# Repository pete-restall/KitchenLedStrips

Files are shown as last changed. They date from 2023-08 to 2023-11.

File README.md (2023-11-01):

# Controller for Under-Cupboard RGB LED Strips
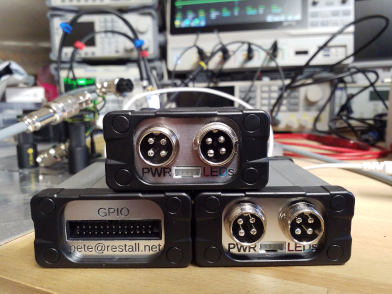
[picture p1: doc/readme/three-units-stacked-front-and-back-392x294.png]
Three Fully Assembled Units

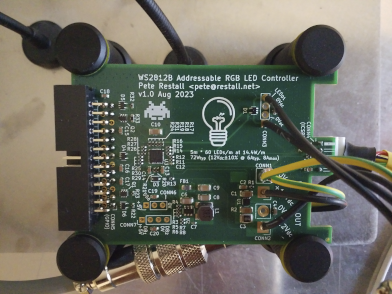
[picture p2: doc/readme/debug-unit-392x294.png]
Debug Unit on the Bench


## What is this ?
My wife wanted our new kitchen to have unobtrusive under-cupboard lighting.  It seemed like a simple and relatively quick project so I decided to have
a bash.  Buying off-the-shelf is boring - there's nothing like building something yourself to see why things work as they do or are priced as they are.
This repository is the result of my effort.

### The LED Strips
The LED strips are adhesive-backed tapes stuffed with RGB '5050' LEDs running at 12V and having a single data line.  The data line is essentially an
SPI MOSI with an implicit 800kHz clock configured as a daisy-chain; there is no start bit as is common with other 'clockless' or one-wire protocols so
the data is encoded using pulse-width modulation, a `1` being a long pulse and a `0` being a short pulse.  The tape has 60 LEDs per metre for a power
consumption of 14.4W/m.  Since the supply rail is 12V there are three '5050' LEDs are driven serially with an [SM16703P](doc/datasheets/leds/SM16703P.pdf)
controller providing a constant current of around 17mA.  The [SM16703P](doc/datasheets/leds/SM16703P.pdf) is _similar_ to the more common
[WS2812B](doc/datasheets/leds/WS2812B.pdf).

### The Slave (LED Controller Board)
The controller board I put together is intended to be very simple with few bells and whistles.  It is based around a
[PIC16F15355](doc/datasheets/mcu/PIC16F15355-DS40001853C.pdf) microcontroller.  The controller is fairly dumb in that it is intended as a slave device,
receiving infrared commands via a [TSOP34440](doc/datasheets/infrared/TSOP34440.pdf) and then handling the generation of a frame buffer and its
serialisation onto the wire.  Each controller can output the frame buffer to one or two LED strips over CY 4-core control cable.  Over-current protection
for the LED strip power rail, as well as under- and over-voltage lock-out, are provided, as is a set of GPIO for future expansion.

The circuit was drawn in KiCad and the board was manufactured and assembled by JLCPCB.  To assemble the unit I soldered the through-hole parts (connectors
and wires) to the board and I cut the enclosure faceplates using a CNC router.  The firmware is written in assembly and is built using
[gputils](https://gputils.sourceforge.io/) since I keep forgetting how the Microchip XC8 compiler seems to deliberately produce bad code; redundant
`goto`s to eat cycles, that sort of thing.  The timing of the LED bitstream is tight enough using this microcontroller that such things matter.

### _[WIP]_ The Master (Voice Commands)
The project is being done in two stages.  The first stage is basic on / off control when you flip a switch.  That has been installed already and works
nicely.  The next stage will (the current work-in-progress) aims to allow voice control of the lighting without internet connectivity - no privacy concerns
or failed lighting when the rural broadband takes a dive.  Voice-to-intent _should not need an internet connection_.  Luckily there are frameworks that do
provide this such as one using an
[STM32F405 microcontroller and Picovoice](https://picovoice.ai/blog/offline-voice-assistant-on-an-stm32-microcontroller/)  A proof-of-concept I knocked
up in Python to control some other RGB LEDs in the house via infrared has shown this can work very well, with no model training required.

## The Repository
There are [Board Schematics](src/schematics).

As well as some [Photographs](doc/bench/photos).

There is the [LED Controller Firmware](src/firmware/lights-gadget).

Plus various [Documentation](doc) including [Datasheets](doc/datasheets).

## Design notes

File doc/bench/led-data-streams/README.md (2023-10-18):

## The Test Fixture
The test fixture is 18x LEDs (6x pixels) split into two partitions of 3x
pixels, ie. there are two strips of LEDs each with their own data wire but
shared +12V$_{dc}$ and 0V rails.

The first strip has its data line (D0) just connected to the cable's wire #3.

The second strip has its data line (D1) connected to the cable's wire #2 and
to the strip's ground via a 470pF 0805 MLCC.  This arrangement lets us compare
the effects of terminating the transmission line wth a moderate capacitance.

The test fixture is connected to the board via 1m of shielded 1mm$^{2}$ CY4
instrumentation cable (PELB0900).  The shielding is connected to the board's
enclosure but stripped back 4cm from the fixture and left unconnected.

## The Board
The board is fully assembled with all internal wiring and external connectors
and is placed inside the extruded aluminium enclosure, ie. a complete unit.

Only one pixel (3x LEDs) of each partition (strip) is addressed by the
firmware for these measurements.

## The Power Supply
The unit is powered by +12V$_{dc}$ supplied by a Rigol DP831 over 50cm of
shielded 1mm$^{2}$ CY4 instrumentation cable (PELB0900).  The shield is
connected to mains earth via the DP831 internally, which in turn connects to
the DUT's enclosure.

## The Oscilloscope
The oscilloscope is a 4-channel 2GHz Siglent SDS6054A.

The oscilloscope CH3 is probing the pad of the LED strip (ie. far-end from
the DUT, after the cable) that corresponds to the first partition (D0).

CH4 is probing the pad of the LED strip (ie. far-end from the DUT, after the
cable) that corresponds to the second partition (D1).

Both probes for D0 and D1 are PCBite 200MHz SP200 10:1.

CH1 is probing the pad corresponding to the +12V$_{dc}$ rail of the first LED
strip of the test fixture, using a Siglent 500MHz SP3050A 10:1 probe.

## The Measurement Results
The results of the measurements can be seen in the PNG screenshots and the
actual samples for channels CH1, CH3 and CH4 have been saved as CSV and are
in the `measurements-as-csv.tar.gz` tarball.

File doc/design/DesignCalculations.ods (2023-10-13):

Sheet: Capacitors
 |  |  | GRM21BR71A106KA73L | GRM155Z71A105KE01 | GRM155Z71A105KE01J | CL10B225KP8NNNC | CL05B104KA5NNNC
Capacitance
Nominal | 100 |  | 10 | 4.7 | 1 | 2.2 | 100
Nominal Adjusted for DC Bias | 92 | Look at the datasheet graphs for this; dependent on bias voltage and physical size | 6.83uF@3.3V, 4.73uF@5V | 3.972uF@3.3V, 3.212uF@5V | 0.598uF@3.3V | 1.95@3.3V | 92nF@5V
Min (-) Initial Tolerance (%) | 10.00% |  | 10.00% | 10.00% | 0.1 | 0.1 | 0.1
Max (+) Initial Tolerance (%) | 10.00% |  | 10.00% | 10.00% | 0.1 | 0.1 | 0.1
Min (-) Temperature Coefficient (%) | 15.00% | X7R is +/- 15% | 15.00% | 15.00% | 0.15 | 0.15 | 0.15
Max (+) Temperature Coefficient (%) | 15.00% |  | 15.00% | 15.00% | 0.15 | 0.15 | 0.15
Min Initial Capacitance | 82.8 |  | 6.147 | 3.5748 | 0.5382 | 1.755 | 82.8
Max Initial Capacitance | 101.2 |  | 7.513 | 4.3692 | 0.6578 | 2.145 | 101.2
Min Capacitance | 69 |  | 5.1225 | 2.979 | 0.4485 | 1.4625 | 69
Max Capacitance | 115 |  | 8.5375 | 4.965 | 0.7475 | 2.4375 | 115
Leakage Current
Insulation Resistance (ohm-Farads) | 1 |  | 50 | 50 | 50 | 484 | 1
Capacitance (uF) | 0.1 |  | 10 | 4.7 | 1 | 2.2 | 0.1
Rated Voltage (V) | 25 |  | 10 | 16 | 10 | 10 | 25
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

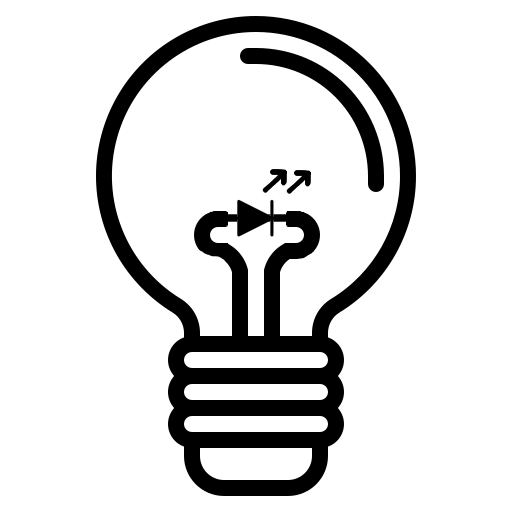
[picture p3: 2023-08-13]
src/schematics/kitchen-led-strips/led-light-bulb.png

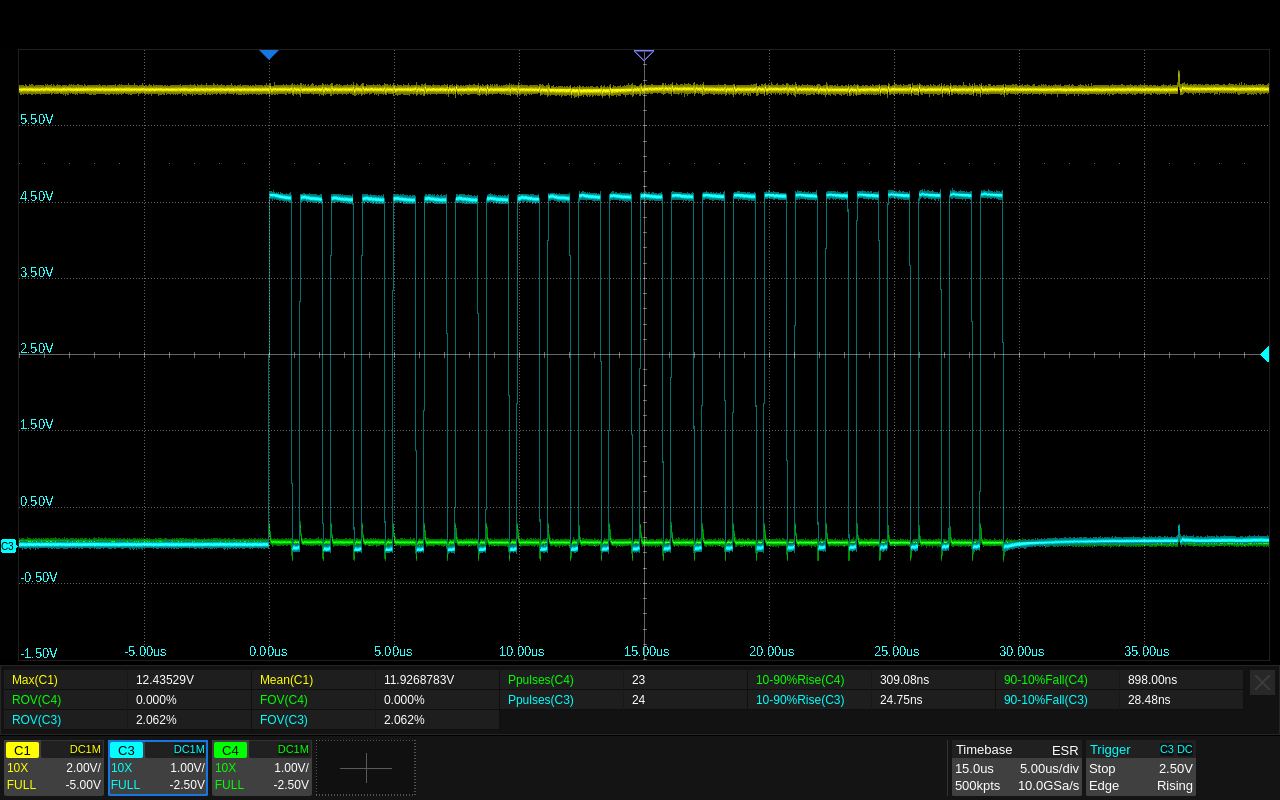
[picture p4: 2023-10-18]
doc/bench/led-data-streams/rgb-ffffff-slew.png

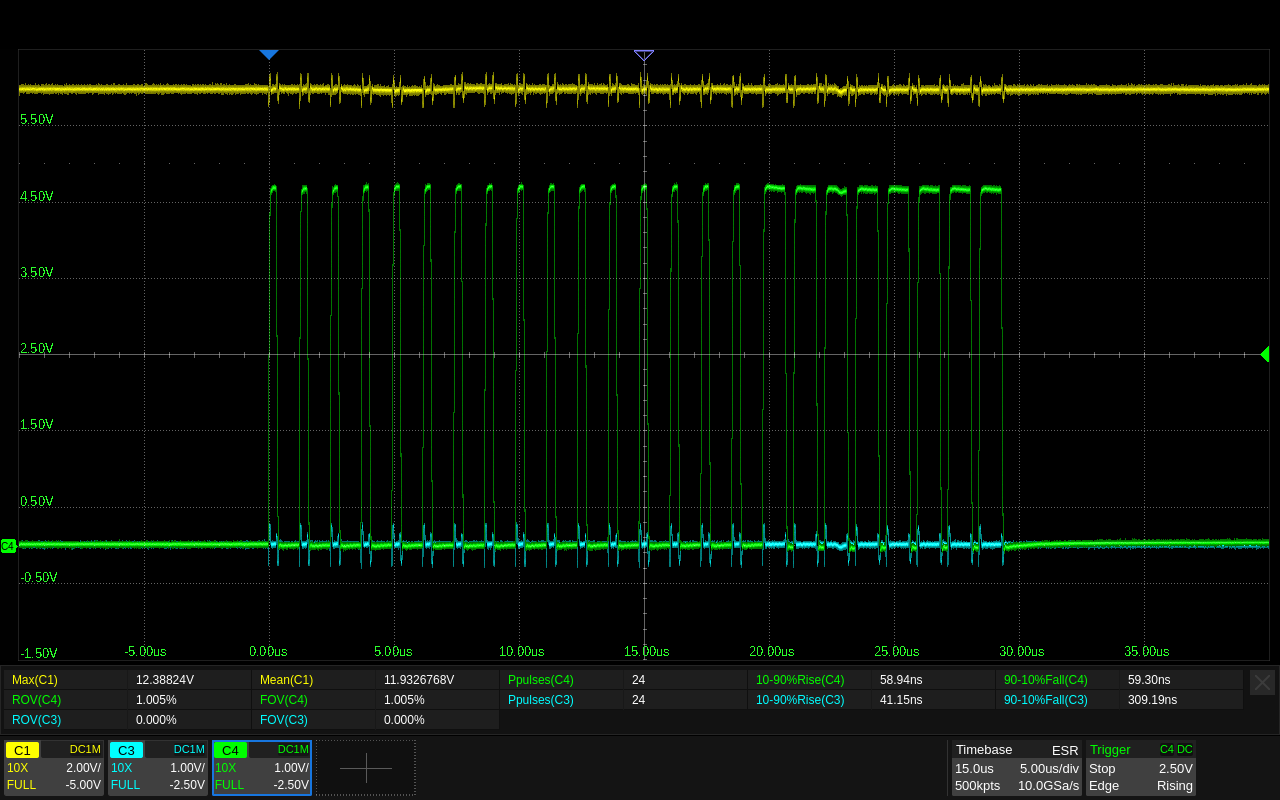
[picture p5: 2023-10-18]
doc/bench/led-data-streams/rgb-0000ff-slew-470pF.png

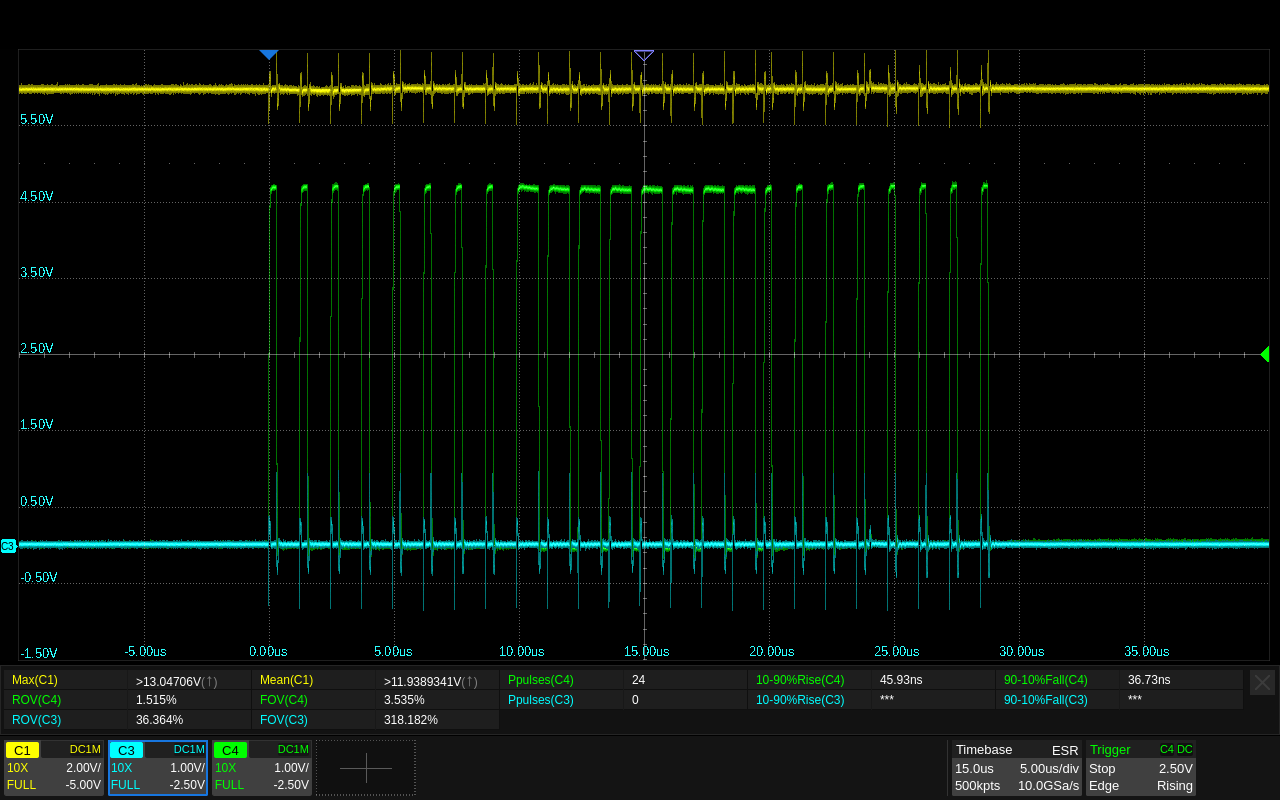
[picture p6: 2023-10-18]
doc/bench/led-data-streams/rgb-ff0000-noslew-470pF.png

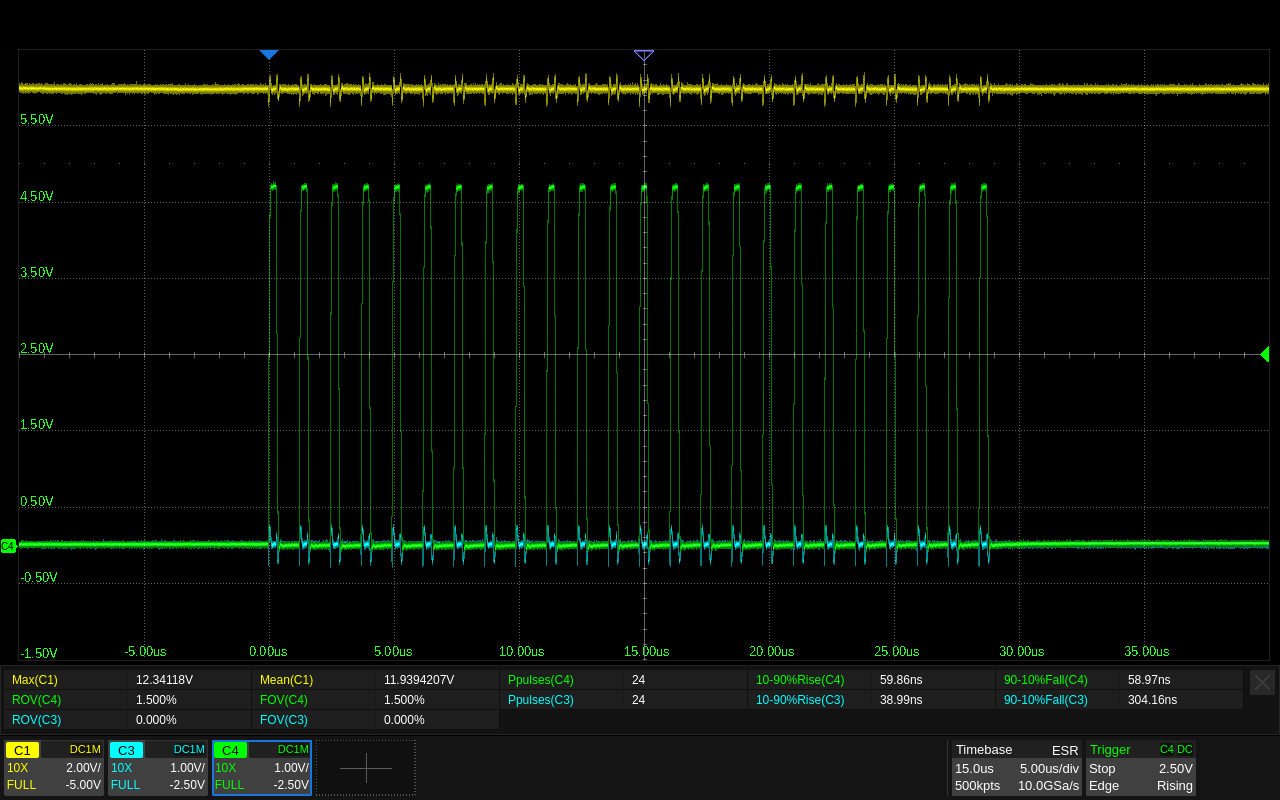
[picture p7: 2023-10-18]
doc/bench/led-data-streams/rgb-000000-slew-470pF.png

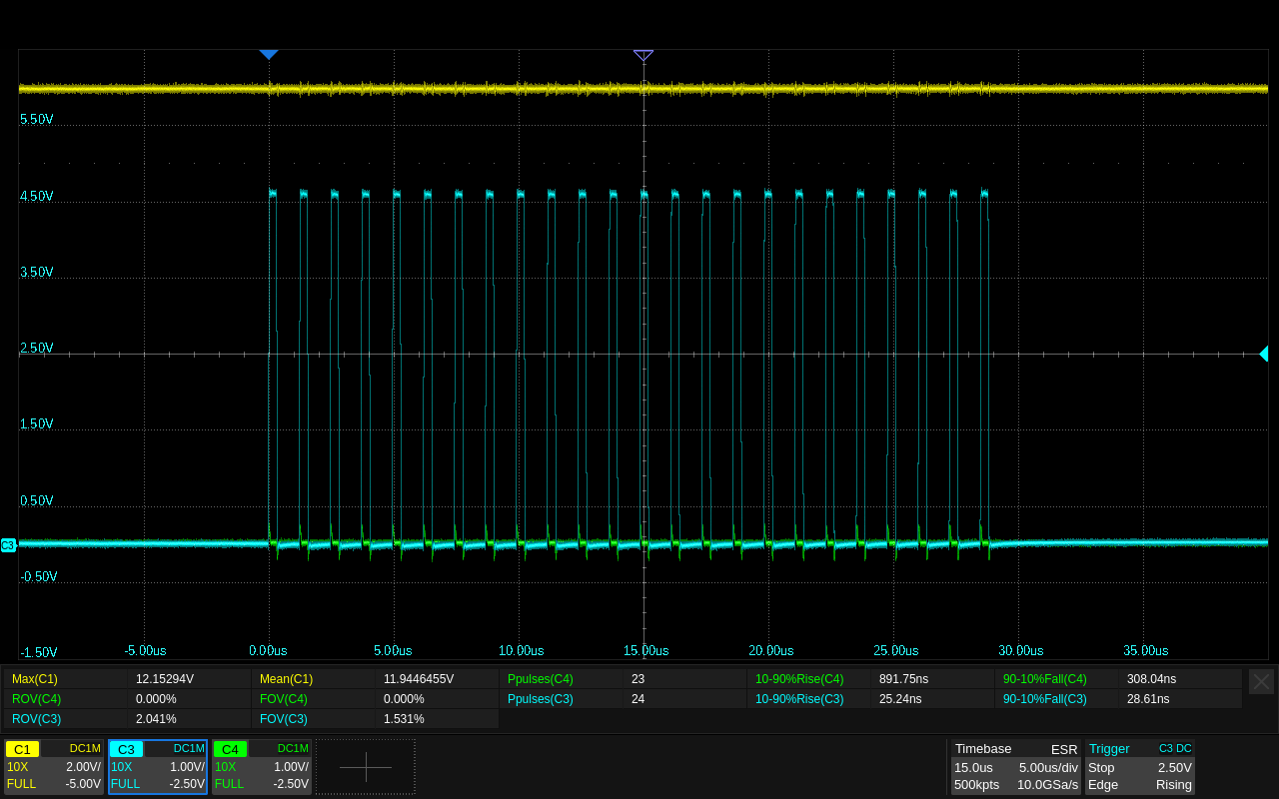
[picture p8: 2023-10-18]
doc/bench/led-data-streams/rgb-000000-slew.png

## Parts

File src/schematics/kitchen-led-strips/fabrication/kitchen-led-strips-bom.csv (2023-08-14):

Comment | Designator | Footprint | LCSC Part Number
VALUE=10μF, PART=CL31B106KAHNFNE (Samsung) or GRM31CR71E106KA12K (Murata) | C1, C3, C6, C8, C9, C10 | 1206 | C307567
VALUE=2.2μF, PART=GRM188Z71E225KE43D (Murata) or GRM188Z71E225ME43D (Murata) | C2, C4, C5, C11, C13, C14, C15, C16, C17, C18, C19, C20 | 0603 | C415535
VALUE=100nF, PART=GRM155R71H104KE14J (Murata) or GMC04X7R104K50NT (Cal-Chip Electronics) | C7 | 0402 | C2649519
VALUE=10nF, PART=885012205067 (Wurth Elektronik) or KGM05AR71E103KH (Kyocera) or CL05B103KB5NNNC (Samsung) | C12 | 0402 | C15195
VALUE=BZA856AVL,115, PART=BZA856AVL,115 (Nexperia) | D1, D2, D4, D5, D6 | SOT-353 | C550063
VALUE=SD103AWS, PART=SD103AWS (Anbon Semi) or RB501V-40_R1_00001 (Panjit Semiconductor) | D3 | SOD-323 | C397613
VALUE=HI0805R800R-10, PART=HI0805R800R-10 (Laird Signal Integrity) or WLBD2012HCU121TH (Walsin) | FB1 | 0805 | C3764520
VALUE=HPC5040NF-3R3M, PART=HPC5040NF-3R3M (Tai Tech) | L1 | HPC5040NF | C357068
VALUE=BC847BS, PART=BC847BS-7-F (Diodes Incorporated) | Q1, Q2 | SOT-363 | C156292
VALUE=10kΩ, PART=RM04F1002CT (Cal-Chip Electronics) or RC0402FR-1310KL (Yageo) | R1, R4, R8, R11, R13, R32 | 0402 | C1858459
VALUE=910Ω, PART=RMCF1210FT910R (Stackpole Electronics) or RC1210FR-07910RL (Yageo) | R2 | 1210 | C3961717
VALUE=30.1kΩ, PART=CR0402-FX-3012GLF (Bourns) or RC0402FR-0730K1L (Yageo) | R3, R6 | 0402 | C138009
VALUE=100kΩ, PART=WR04X1003FTL (Walsin) or CR0402-FX-1003GLF (Bourns) | R5 | 0402 | C163806
VALUE=52.3kΩ, PART=CR0402-FX-5232GLF (Bourns) or RC0402FR-0752K3L (Yageo) | R7 | 0402 | C2085465
VALUE=634Ω, PART=RC0402FR-07634RL (Yageo) or CR0402-FX-6340GLF (Bourns) | R9, R10, R12, R24, R25, R26, R27, R28, R31 | 0402 | C327330
VALUE=91Ω, PART=RC0402FR-0791RL (Yageo) or RMCF0402FT91R0 (Stackpole Electronics) | R14, R15, R16, R17, R18, R19, R20, R21 | 0402 | C137926
VALUE=4.7kΩ, PART=WR04X4701FTL (Walsin) or RC0402FR-134K7L (Yageo) | R22, R23, R29, R30 | 0402 | C163826
VALUE=7.5Ω, PART=CRCW06037R50FKEA (Vishay Dale) or RT0603FRE077R5L (Yageo) | R33 | 0603 | C4022234
VALUE=DML3006LFDS, PART=DML3006LFDS-7 (Diodes Incorporated) | U1 | V-DFN2020-8 | C2149933
VALUE=AP62150WU, PART=AP62150WU (Diodes Incorporated) | U2 | TSOT-26 | C3194237
VALUE=PIC16F15355-I/MV, PART=PIC16F15355-I/MV (Microchip) | U3 | UQFN28 | C637824

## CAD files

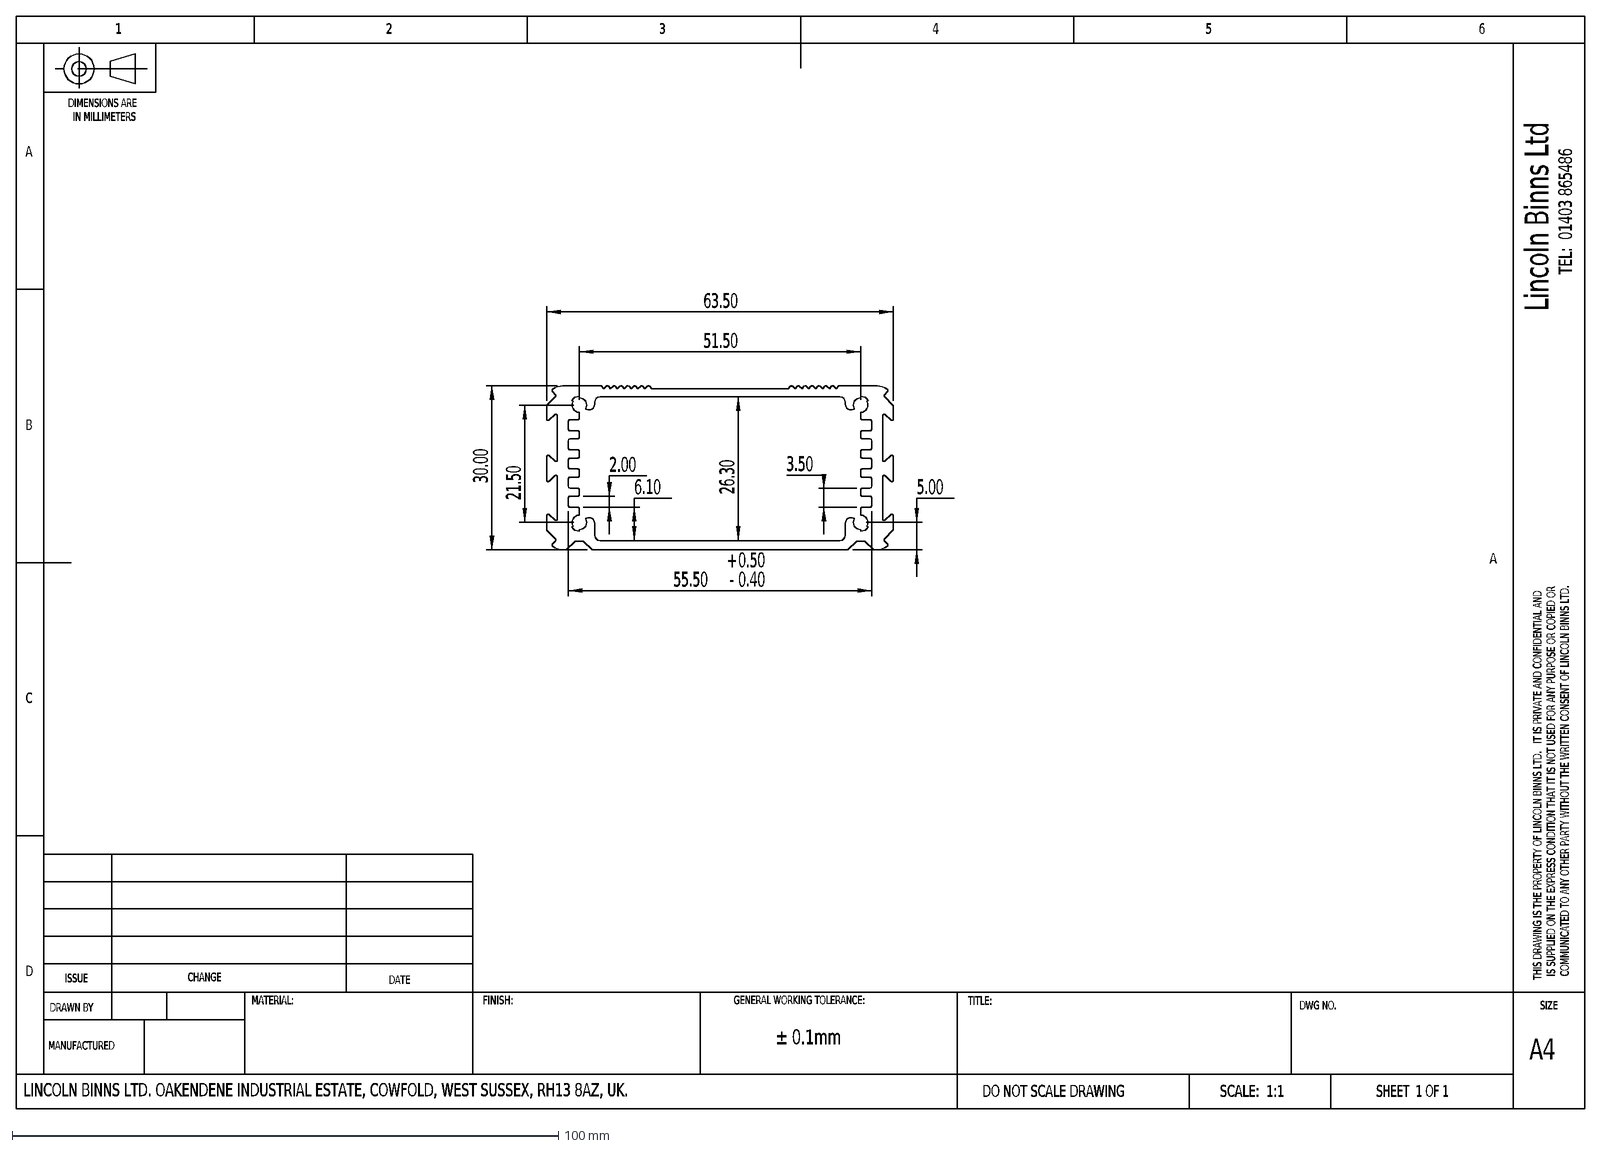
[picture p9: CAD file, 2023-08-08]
doc/datasheets/enclosure/e-case_a_dimensions.dxf
B
C
D
A
3
2
1
4
5
6
DIMENSIONS ARE
IN MILLIMETERS
FINISH:
MATERIAL:
DO NOT SCALE DRAWING
CHANGE
TITLE:
DWG NO.
SCALE: 1:1
SHEET 1 OF 1
A4
GENERAL WORKING TOLERANCE:
DRAWN BY
MANUFACTURED
SIZE
THIS DRAWING IS THE PROPERTY OF LINCOLN BINNS LTD. IT IS PRIVATE AND CONFIDENTIAL AND
IS SUPPLIED ON THE EXPRESS CONDITION THAT IT IS NOT USED FOR ANY PURPOSE OR COPIED OR
COMMUNICATED TO ANY OTHER PARTY WITHOUT THE WRITTEN CONSENT OF LINCOLN BINNS LTD.
Lincoln Binns Ltd
± 0.1mm
ISSUE
DATE
LINCOLN BINNS LTD. OAKENDENE INDUSTRIAL ESTATE, COWFOLD, WEST SUSSEX, RH13 8AZ, UK.
TEL: 01403 865486
63.50
51.50
30.00
26.30
6.10
2.00
3.50
55.50
+
-
0.50
0.40
21.50
5.00

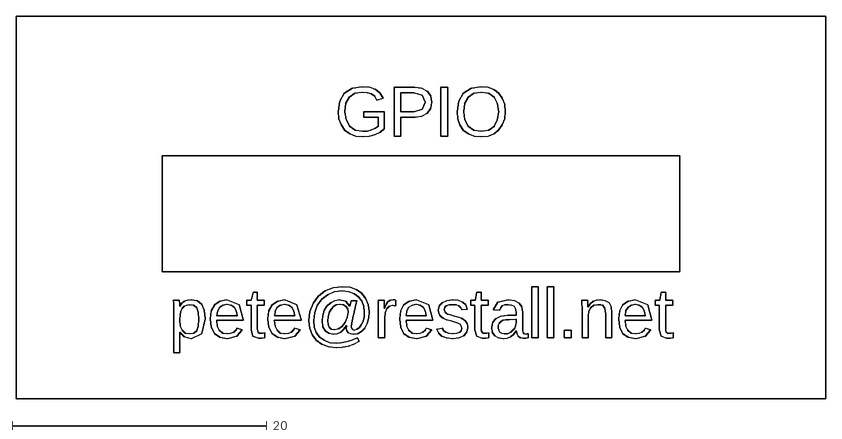
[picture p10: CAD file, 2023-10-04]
src/enclosure/front-plate.dxf
63.5 x 30.0

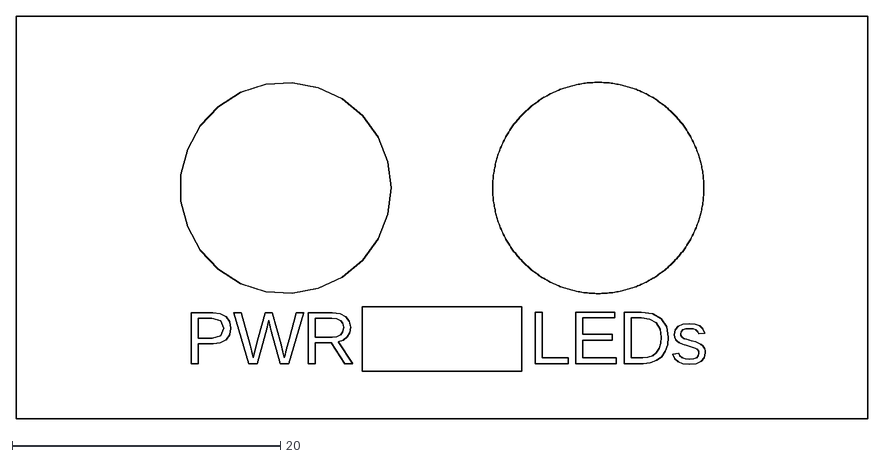
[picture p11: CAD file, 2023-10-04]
src/enclosure/back-plate.dxf
63.5 x 30.0

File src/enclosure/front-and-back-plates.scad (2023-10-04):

function mm(x) = x;

isDrawingFrontPlate = true;
isProjectionForDxfExport = true;

plateWidth = mm(63.5);
plateHeight = mm(30);
plateThickness = mm(1.6);
plateThroughHole = plateThickness + mm(0.2);
plateEngraving = mm(0.16);

icspConnectorWidth = mm(11.9);
icspConnectorHeight = mm(4.8);
gpioConnectorWidth = mm(40.62);
gpioConnectorHeight = mm(9.1);
circularConnectorRadius = mm(15.74 / 2);

topOfPcb = -mm(5.05);
bottomOfPcb = topOfPcb - mm(1.6);

module frontPlate(plateEngraving) {
	difference() {
		cube([plateWidth, plateHeight, plateThickness], center=true);

		translate([0, topOfPcb + gpioConnectorHeight / 2, 0])
			cube([gpioConnectorWidth, gpioConnectorHeight, plateThroughHole], center=true);

	translate([0, gpioConnectorHeight / 2 + mm(1), plateThickness / 2 - plateEngraving])
		linear_extrude(height=plateEngraving + mm(0.1), center=false) text("GPIO", size=4, halign="center", valign="bottom");

	translate([0, -gpioConnectorHeight / 2 - mm(1.75), plateThickness / 2 - plateEngraving])
		linear_extrude(height=plateEngraving + mm(0.1), center=false) text("pete@restall.net", size=4, halign="center", valign="top");
	}
}

module backPlate(plateEngraving) {
	difference() {
		cube([plateWidth, plateHeight, plateThickness], center=true);

		translate([-mm(11.65), mm(2.2), 0])
			cylinder(h=plateThroughHole, r=circularConnectorRadius, center=true);

		translate([mm(11.65), mm(2.2), 0])
			cylinder(h=plateThroughHole, r=circularConnectorRadius, center=true, $fn=360);

		translate([0, bottomOfPcb - icspConnectorHeight / 2, 0])
			cube([icspConnectorWidth, icspConnectorHeight, plateThroughHole], center=true, $fn=360);

	translate([-mm(6.5), bottomOfPcb - icspConnectorHeight / 2, plateThickness / 2 - plateEngraving])
		linear_extrude(height=plateEngraving + mm(0.1), center=false) text("PWR", size=4, halign="right", valign="center");

	translate([mm(6.5), bottomOfPcb - icspConnectorHeight / 2, plateThickness / 2 - plateEngraving])
		linear_extrude(height=plateEngraving + mm(0.1), center=false) text("LEDs", size=4, halign="left", valign="center");
	}
}

module drawPart(plateEngraving=plateEngraving) {
	if (isDrawingFrontPlate)
		frontPlate(plateEngraving);
	else
		backPlate(plateEngraving);
}

if (isProjectionForDxfExport)
	projection(cut=false) drawPart(plateEngraving=plateThroughHole);
else
	drawPart();

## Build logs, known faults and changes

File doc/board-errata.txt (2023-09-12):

PCB / Hardware Errata
=====================
v1.0:
	Pin 6 (RA7) of U3 is utilised as the infrared receiver's data line, backed
	by a UART RX in the firmware.  However, the PPS module of the PIC16F15355
	does not allow UART functions to be mapped to PORTA pins.  A bodge wire
	is required from pin 6 (RA7) to pin 18 (RB0) to allow mapping.  This
	bodge wire is accomplished by dedicating a CLC module in the firmware,
	thus no soldering is required.

	Pin 18 (RB0) is no longer available for the DEBUG0 functions as it has
	been repurposed as the infrared receiver's data line (UART RX from RA7).

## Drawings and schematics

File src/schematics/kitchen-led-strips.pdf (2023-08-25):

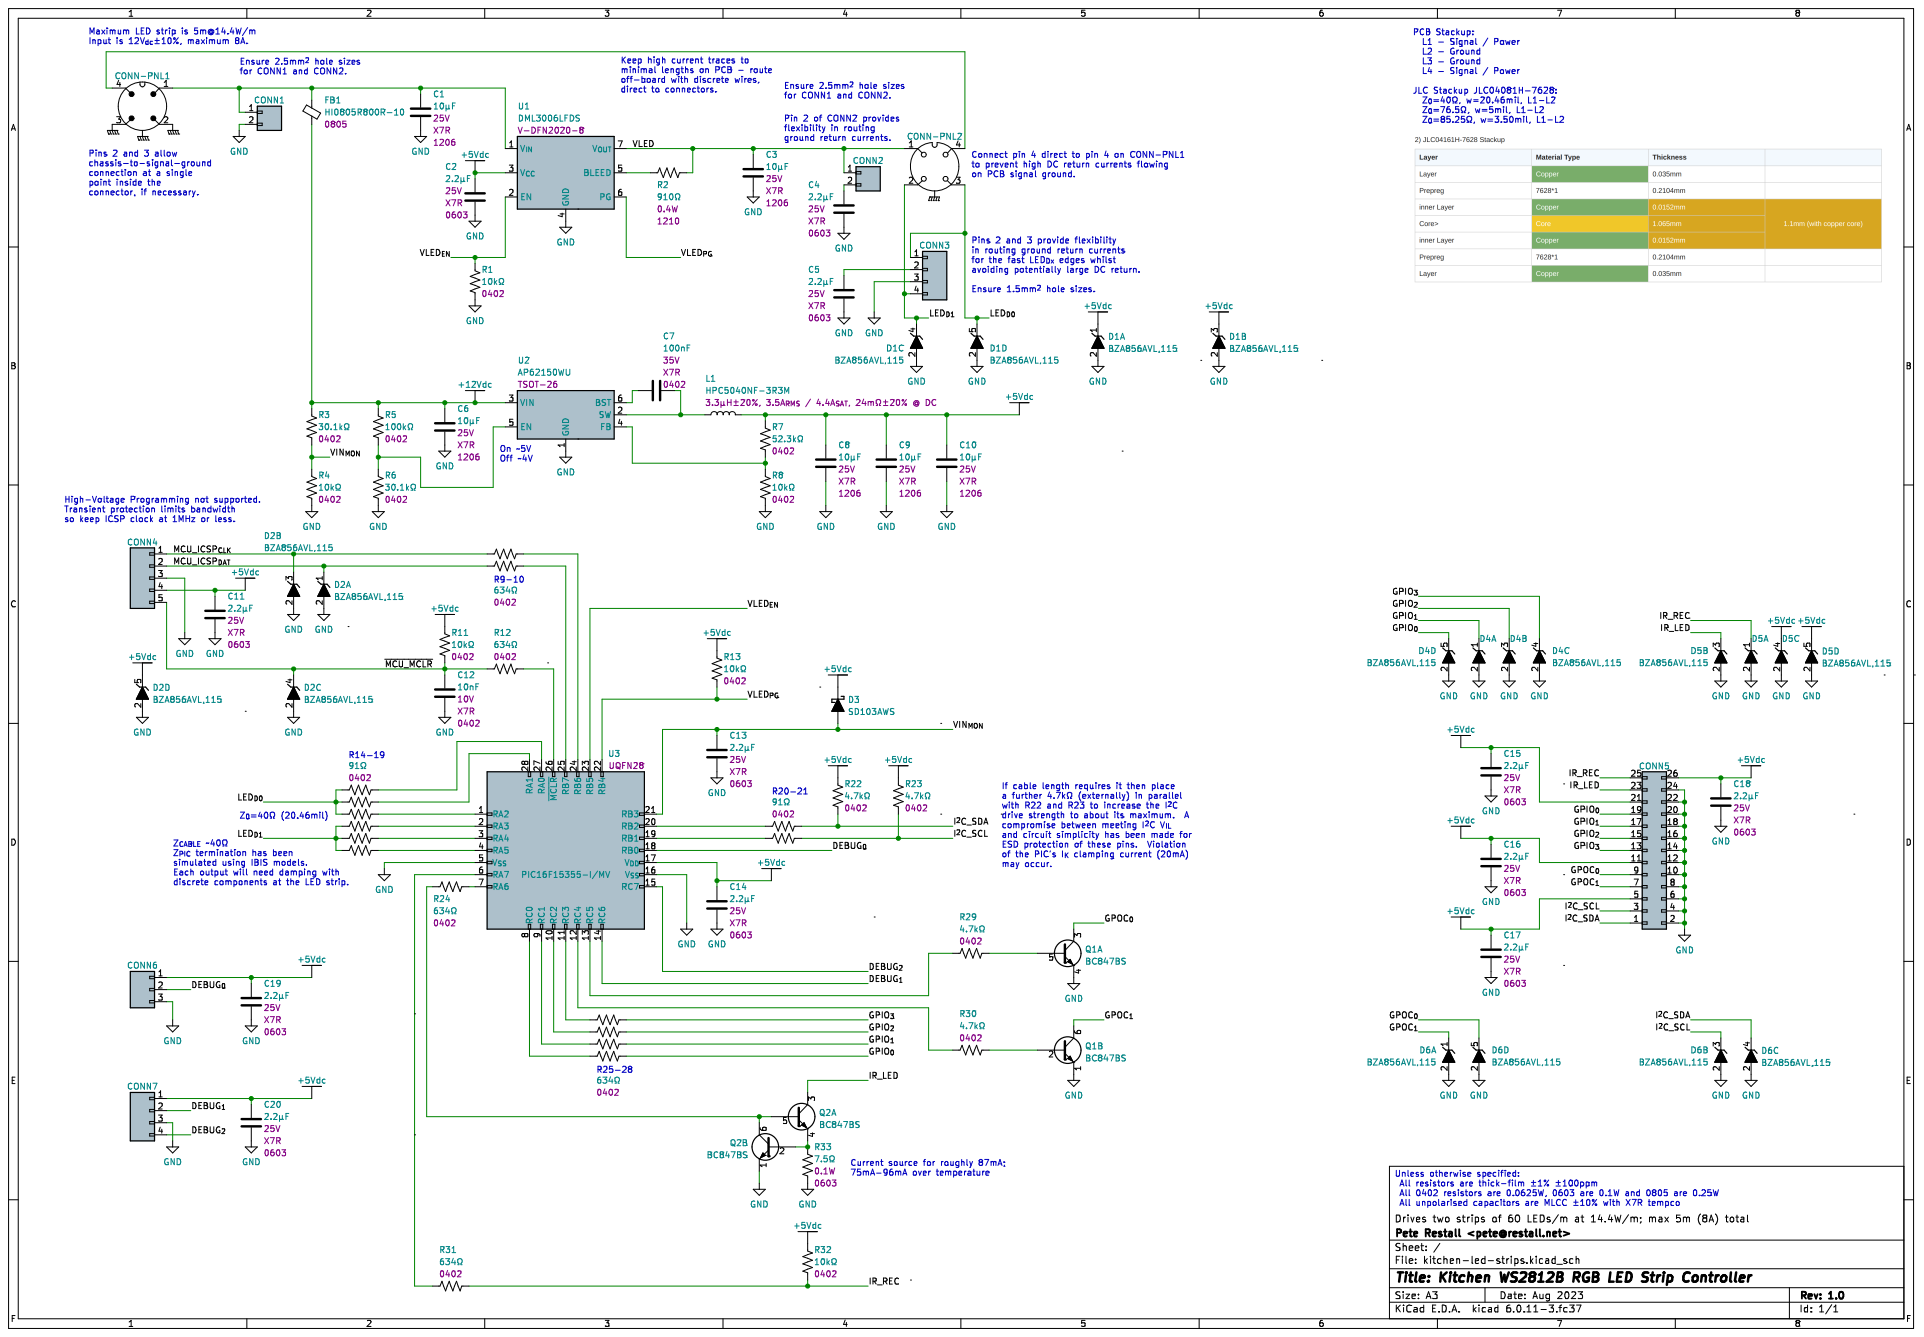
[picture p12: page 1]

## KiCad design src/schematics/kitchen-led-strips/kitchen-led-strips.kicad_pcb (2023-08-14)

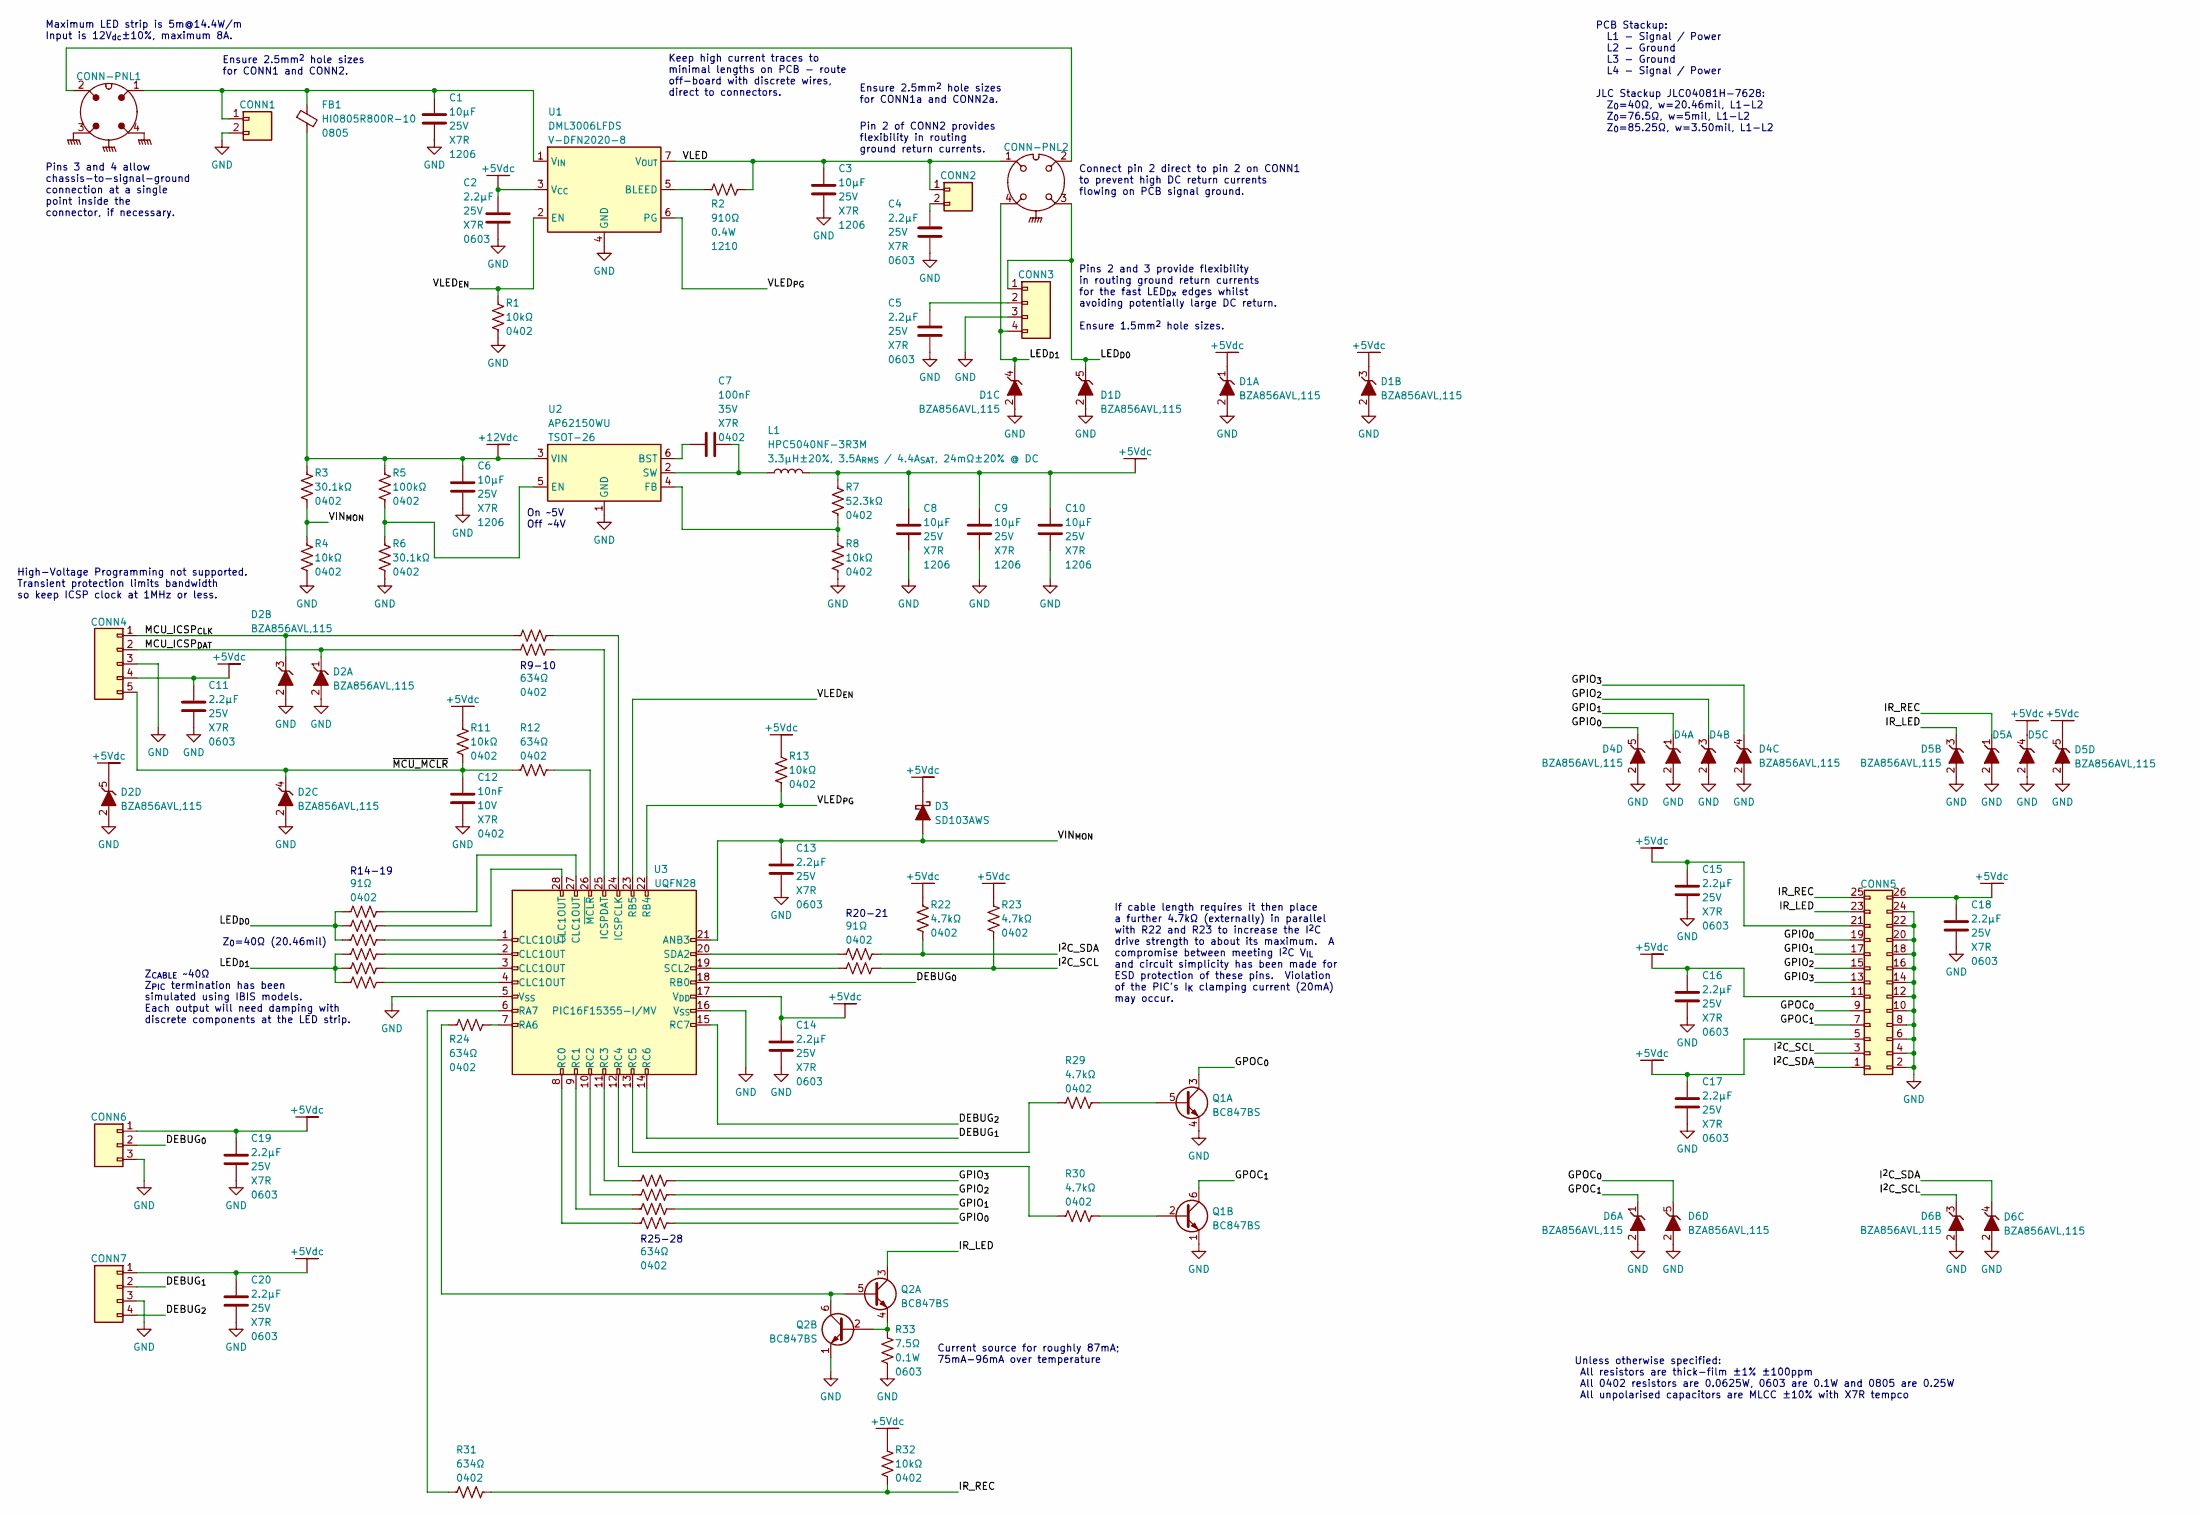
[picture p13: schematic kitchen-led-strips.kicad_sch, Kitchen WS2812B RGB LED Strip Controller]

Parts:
C1, C3, C6, C8, C9, C10: 10μF; unpolarised-nominal-1206-3216; Tolerance ±10%; VoltageRating 25V; ManufacturerPartNumber CL31B106KAHNFNE
C2, C4, C5, C11, C13, C14, C15, C16, C17, C18, C19, C20: 2.2μF; unpolarised-nominal-0603-1608; Tolerance ±10%; VoltageRating 25V; ManufacturerPartNumber GRM188Z71E225KE43D
C7: 100nF; unpolarised-nominal-0402-1005; Tolerance ±10%; VoltageRating 35V; ManufacturerPartNumber GRM155R71H104KE14J
C12: 10nF; unpolarised-nominal-0402-1005; Tolerance ±10%; VoltageRating 10V; ManufacturerPartNumber 885012205067
CONN1, CONN2: DNP; th-pads-1x2-5.08mm-vertical-2.5mm^2-solder-pads
CONN3, CONN7: DNP; th-header-1x4-2.54mm-vertical
CONN4: S5B-PH-K-S; S5B-PH-K-?; ManufacturerPartNumber S5B-PH-K-S
CONN5: header-2x13-row; th-header-2x13-2.54mm-row-horizontal-shrouded; ManufacturerPartNumber 19-0045
CONN6: DNP; th-header-1x3-2.54mm-vertical
CONN-PNL1, CONN-PNL2: PSG01593; ManufacturerPartNumber PSG01593
D1, D2, D4, D5, D6: BZA856AVL,115; SOT-353; ManufacturerPartNumber BZA856AVL,115
D3: SD103AWS; SOD-323; ManufacturerPartNumber SD103AWS
FB1: HI0805R800R-10; FB0805; ManufacturerPartNumber HI0805R800R-10
L1: HPC5040NF-3R3M; HPC5040NF; Tolerance ±20%; ManufacturerPartNumber HPC5040NF-3R3M
Q1, Q2: BC847BS; SOT-363; ManufacturerPartNumber BC847BS-7-F
R1, R4, R8, R11, R13, R32: 10kΩ; nominal-0402-1005; Tolerance ±1%; ManufacturerPartNumber RM04F1002CT
R2: 910Ω; nominal-1210-3225; Tolerance ±1%; ManufacturerPartNumber RMCF1210FT910R
R3, R6: 30.1kΩ; nominal-0402-1005; Tolerance ±1%; ManufacturerPartNumber CR0402-FX-3012GLF
R5: 100kΩ; nominal-0402-1005; Tolerance ±1%; ManufacturerPartNumber WR04X1003FTL
R7: 52.3kΩ; nominal-0402-1005; Tolerance ±1%; ManufacturerPartNumber CR0402-FX-5232GLF
R9, R10, R12, R24, R25, R26, R27, R28, R31: 634Ω; nominal-0402-1005; Tolerance ±1%; ManufacturerPartNumber RC0402FR-07634RL
R14, R15, R16, R17, R18, R19, R20, R21: 91Ω; nominal-0402-1005; Tolerance ±1%; ManufacturerPartNumber RC0402FR-0791RL
R22, R23, R29, R30: 4.7kΩ; nominal-0402-1005; Tolerance ±1%; ManufacturerPartNumber WR04X4701FTL
R33: 7.5Ω; nominal-0603-1608; Tolerance ±1%; ManufacturerPartNumber CRCW06037R50FKEA
U1: DML3006LFDS; V-DFN2020-8; ManufacturerPartNumber DML3006LFDS-7
U2: AP62150WU; TSOT-26; ManufacturerPartNumber AP62150WU
U3: PIC16F15355-I/MV; UQFN28-4x4mm-0.4mm-expad-2.35x2.35mm-thermvias; ManufacturerPartNumber PIC16F15355-I/MV

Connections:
+5Vdc: C2.1, C8.1, C9.1, C10.1, C11.1, C14.1, C15.1, C16.1, C17.1, C18.1, C19.1, C20.1, CONN4.4, CONN5.5, CONN5.11, CONN5.21, CONN5.26, CONN6.1, CONN7.1, D1.1 (K), D1.3 (K), D2.5 (K), D3.1 (K), D5.4 (K), D5.5 (K), L1.2 (P2_PWROUT), R7.1, R11.1, R13.1, R22.1, R23.1, R32.1, U1.3 (V_{CC}), U3.17 (V_{DD})
+12V_{dc}: C6.1, FB1.2 (P2_PWROUT), R3.1, R5.1, U2.3 (VIN)
/DEBUG_{0}: CONN6.2, U3.18 (RB0)
/DEBUG_{1}: CONN7.2, U3.14 (RC6)
/DEBUG_{2}: CONN7.4, U3.15 (RC7)
/GPIO_{0}: CONN5.19, D4.5 (K), R28.1
/GPIO_{1}: CONN5.17, D4.1 (K), R27.1
/GPIO_{2}: CONN5.15, D4.3 (K), R26.1
/GPIO_{3}: CONN5.13, D4.4 (K), R25.1
/GPOC_{0}: CONN5.9, D6.5 (K), Q1.3 (C)
/GPOC_{1}: CONN5.7, D6.1 (K), Q1.6 (C)
/IR_LED: CONN5.23, D5.3 (K), Q2.3 (C)
/IR_REC: CONN5.25, D5.1 (K), R31.2, R32.2
/I^{2}C_SCL: CONN5.3, D6.3 (K), R21.1, R23.2
/I^{2}C_SDA: CONN5.1, D6.4 (K), R20.1, R22.2
/LED_{D0}: CONN3.1, CONN-PNL2.3, D1.5 (K), R14.2, R15.2, R16.2
/LED_{D1}: CONN3.4, CONN-PNL2.4, D1.4 (K), R17.2, R18.2, R19.2
/MCU_ICSP_{CLK}: CONN4.1, D2.3 (K), R9.2
/MCU_ICSP_{DAT}: CONN4.2, D2.1 (K), R10.2
/VIN_{MON}: C13.1, D3.2 (A), R3.2, R4.1, U3.21 (ANB3)
/VLED: C3.1, CONN2.1, CONN-PNL2.1, R2.2, U1.7 (V_{OUT}), U1.8 (V_{OUT})
/VLED_{EN}: R1.1, U1.2 (EN), U3.23 (RB5)
/VLED_{PG}: R13.2, U1.6 (PG), U3.22 (RB4)
/~MCU_MCLR: C12.1, CONN4.5, D2.4 (K), R11.2, R12.1
GND: C1.2, C2.2, C3.2, C4.2, C5.2, C6.2, C8.2, C9.2, C10.2, C11.2, C12.2, C13.2, C14.2, C15.2, C16.2, C17.2, C18.2, C19.2, C20.2, CONN1.2 (P2_PWROUT), CONN3.3, CONN4.3, CONN5.2, CONN5.4, CONN5.6, CONN5.8, CONN5.10, CONN5.12, CONN5.14, CONN5.16, CONN5.18, CONN5.20, CONN5.22, CONN5.24, CONN6.3, CONN7.3, D1.2 (A), D2.2 (A), D4.2 (A), D5.2 (A), D6.2 (A), Q1.1 (E), Q1.4 (E), Q2.1 (E), R1.2, R4.2, R6.2, R8.2, R33.2, U1.4 (GND), U2.1 (GND), U3.5 (V_{SS}), U3.16 (V_{SS}), U3.29 (V_{SS})
unnamed: C1.1, CONN1.1, CONN-PNL1.1, FB1.1 (P1_PWRIN), U1.1 (V_{IN}), U1.9 (V_{IN})
unnamed: C4.1, CONN2.2
unnamed: C5.1, CONN3.2
unnamed: C7.1, U2.6 (BST)
unnamed: C7.2, L1.1, U2.2 (SW)
unnamed: CONN-PNL1.2, CONN-PNL2.2
unnamed: CONN-PNL1.3, CONN-PNL1.4
unnamed: Q1.2 (B), R30.2
unnamed: Q1.5 (B), R29.2
unnamed: Q2.2 (B), Q2.4 (E), R33.1
unnamed: Q2.5 (B), Q2.6 (C), R24.1
unnamed: R2.1, U1.5 (BLEED)
unnamed: R5.2, R6.1, U2.5 (EN)
unnamed: R7.2, R8.1, U2.4 (FB)
unnamed: R9.1, U3.24 (ICSPCLK)
unnamed: R10.1, U3.25 (ICSPDAT)
unnamed: R12.2, U3.26 (~MCLR)
unnamed: R14.1, U3.27 (CLC1OUT)
unnamed: R15.1, U3.28 (CLC1OUT)
unnamed: R16.1, U3.1 (CLC1OUT)
unnamed: R17.1, U3.2 (CLC1OUT)
unnamed: R18.1, U3.3 (CLC1OUT)
unnamed: R19.1, U3.4 (CLC1OUT)
unnamed: R20.2, U3.20 (SDA2)
unnamed: R21.2, U3.19 (SCL2)
unnamed: R24.2, U3.7 (RA6)
unnamed: R25.2, U3.11 (RC3)
unnamed: R26.2, U3.10 (RC2)
unnamed: R27.2, U3.9 (RC1)
unnamed: R28.2, U3.8 (RC0)
unnamed: R29.1, U3.13 (RC5)
unnamed: R30.1, U3.12 (RC4)
unnamed: R31.1, U3.6 (RA7)

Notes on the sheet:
Pin 2 of CONN2 provides flexibility in routing ground return currents.
Z_{0}=40Ω (20.46mil)
R20-21
PCB Stackup: L1 - Signal / Power L2 - Ground L3 - Ground L4 - Signal / Power JLC Stackup JLC04081H-7628: Z_{0}=40Ω, w=20.46mil, L1-L2 Z_{0}=76.5Ω, w=5mil, L1-L2 Z_{0}=85.25Ω, w=3.50mil, L1-L2
High-Voltage Programming not supported. Transient protection limits bandwidth so keep ICSP clock at 1MHz or less.
Maximum LED strip is 5m@14.4W/m Input is 12V_{dc}±10%, maximum 8A.
Current source for roughly 87mA; 75mA-96mA over temperature
Unless otherwise specified: All resistors are thick-film ±1% ±100ppm All 0402 resistors are 0.0625W, 0603 are 0.1W and 0805 are 0.25W All unpolarised capacitors are MLCC ±10% with X7R tempco
Pins 2 and 3 provide flexibility in routing ground return currents for the fast LED_{Dx} edges whilst avoiding potentially large DC return. Ensure 1.5mm^{2} hole sizes.
R14-19
Z_{CABLE} ~40Ω Z_{PIC} termination has been simulated using IBIS models. Each output will need damping with discrete components at the LED strip.
Keep high current traces to minimal lengths on PCB - route off-board with discrete wires, direct to connectors.
If cable length requires it then place a further 4.7kΩ (externally) in parallel with R22 and R23 to increase the I^{2}C drive strength to about its maximum. A compromise between meeting I^{2}C V_{IL} and circuit simplicity has been made for ESD protection of these pins. Violation of the PIC's I_{K}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
Connect pin 2 direct to pin 2 on CONN1 to prevent high DC return currents flowing on PCB signal ground.
R9-10
Ensure 2.5mm^{2} hole sizes for CONN1a and CONN2a.
Pins 3 and 4 allow chassis-to-signal-ground connection at a single point inside the connector, if necessary.
R25-28
Ensure 2.5mm^{2} hole sizes for CONN1 and CONN2.
On ~5V Off ~4V

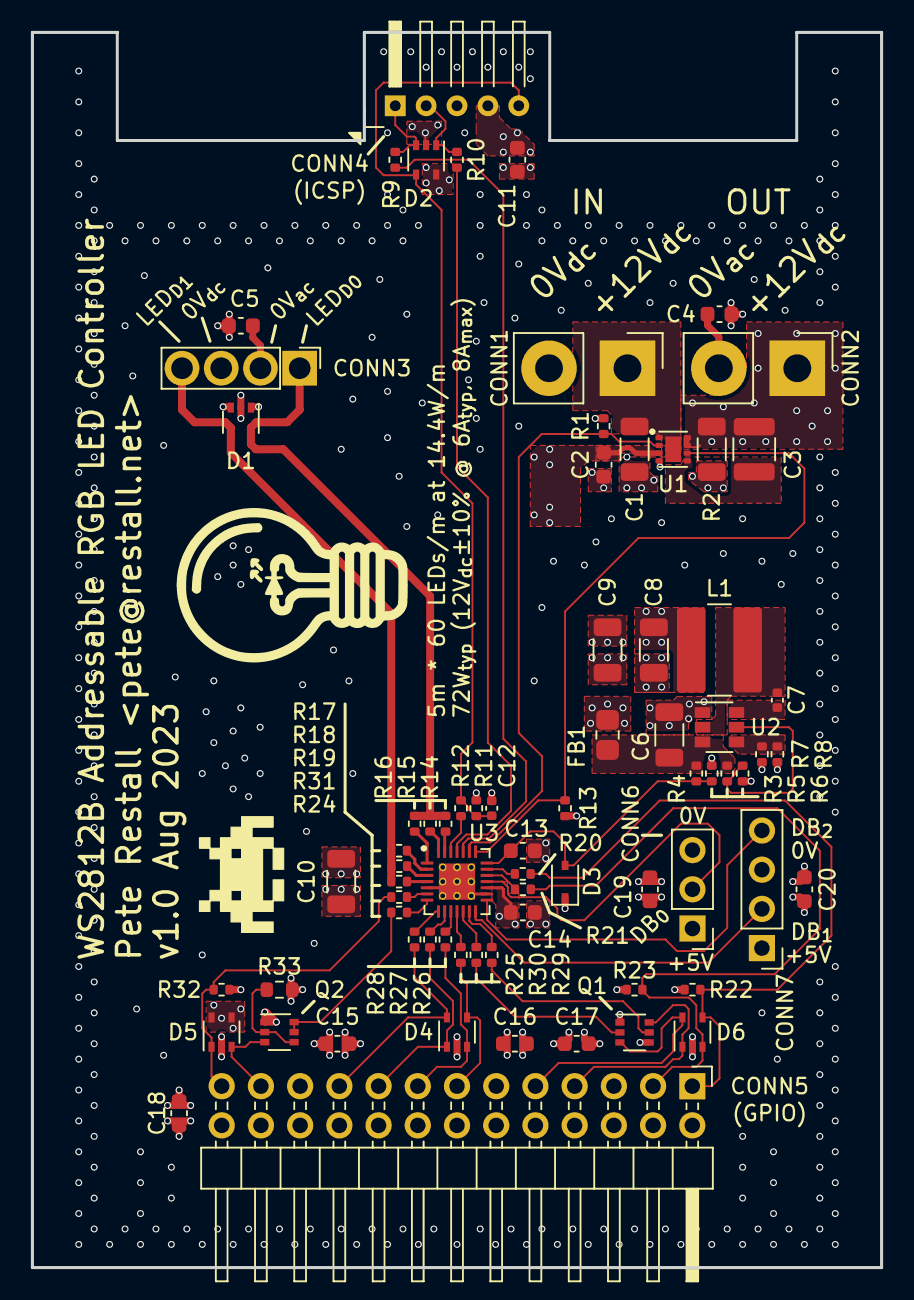
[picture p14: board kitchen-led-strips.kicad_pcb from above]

Board: 4 copper layers, 55.0 x 80.0 mm, 73 parts (0 on the bottom side), 56 nets.

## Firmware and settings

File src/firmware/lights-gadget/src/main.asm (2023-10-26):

	#define __KITCHENLEDS_MAIN_ASM

	#include "commands.inc"
	#include "config.inc"
	#include "initialise.inc"
	#include "led-patterns.inc"
	#include "main.inc"
	#include "mcu.inc"
	#include "power-management.inc"
	#include "power-supply.inc"
	#include "reset.inc"
	#include "rgb-leds.inc"

	radix decimal

_FLAG_POWER_SUPPLY_ENABLED equ 0

.mainUdata udata
	global mainTimebaseLow
	global mainTimebaseHigh
mainTimebaseLow res 1
mainTimebaseHigh res 1
_isMorePollingRequired res 1
_flags res 1

.main code
	global main

main:
_initialise:
	pagesel initialise
	call initialise

	banksel _flags
	clrf _flags

	banksel INTCON
	bsf INTCON, PEIE
	bsf INTCON, GIE

	banksel mainTimebaseLow
	clrf mainTimebaseLow
	clrf mainTimebaseHigh

_enablePowerToLedsOnlyIfPowerOnResetOrBrownOutOrMasterClear:
	#if (CONFIG_DEFAULT_LIGHTS_ON != 0)

	pagesel resetGetTypeFlags
	call resetGetTypeFlags
	andlw (1 << _RESET_TYPE_FLAG_POR) | (1 << _RESET_TYPE_FLAG_BOR) | (1 << _RESET_TYPE_FLAG_MCLR)

	pagesel powerSupplyEnable
	btfss STATUS, Z
	call powerSupplyEnable

	#endif

	; !!! TODO: START OF TEMPORARY DEBUGGING (ENABLE POWER SWITCH FOR LEDS AND DISABLE INTERLACING) !!!
	pagesel ledPatternsBicolourInterlacedDisableInterlacing
	call ledPatternsBicolourInterlacedDisableInterlacing
	; !!! TODO: END OF TEMPORARY DEBUGGING !!!

_pollingLoop:
	clrwdt

_startPolling:
	banksel _isMorePollingRequired
	clrf _isMorePollingRequired

_pollPowerSupplyModule:
	pagesel powerSupplyPoll
	call powerSupplyPoll
	banksel _isMorePollingRequired
	iorwf _isMorePollingRequired, F

_forceBlitToAvoidFlashIfPowerSupplyHasBeenEnabledSinceLastPoll:
	pagesel powerSupplyIsEnabled
	call powerSupplyIsEnabled
	xorlw 0

	banksel _flags
	btfsc _flags, _FLAG_POWER_SUPPLY_ENABLED
	xorlw 1

	btfsc STATUS, Z
	bra _noNeedToForceBlit

	movlw (1 << _FLAG_POWER_SUPPLY_ENABLED)
	xorwf _flags, F

	pagesel rgbLedsForceNextBlitBeforeFrameSync
	btfss STATUS, Z
	call rgbLedsForceNextBlitBeforeFrameSync

_noNeedToForceBlit:

_pollRgbLedsModule:
	pagesel rgbLedsPoll
	call rgbLedsPoll
	banksel _isMorePollingRequired
	iorwf _isMorePollingRequired, F

_incrementMainTimebaseIfFrameCounterHasChanged:
	banksel rgbLedsFrameCounter
	movf rgbLedsFrameCounter, W

	banksel mainTimebaseLow
	xorwf mainTimebaseLow, W
	btfsc STATUS, Z
	bra _frameCounterUnchanged

	incf mainTimebaseLow, F
	btfsc STATUS, Z
	incf mainTimebaseHigh, F

_frameCounterUnchanged:
_pollLedPatternsModule:
	pagesel ledPatternsPoll
	call ledPatternsPoll
	banksel _isMorePollingRequired
	iorwf _isMorePollingRequired, F

_pollCommandsModule:
	pagesel commandsPoll
	call commandsPoll
	banksel _isMorePollingRequired
	iorwf _isMorePollingRequired, F

_sleepIfNoMorePollingIsRequired:
	banksel _isMorePollingRequired
	movf _isMorePollingRequired, F
	btfss STATUS, Z
	bra _pollingLoop

	pagesel powerManagementSleep
	call powerManagementSleep
	bra _pollingLoop

	end

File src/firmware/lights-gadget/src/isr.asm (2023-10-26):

	#include "config.inc"
	#include "isr.inc"
	#include "mcu.inc"
	#include "power-supply.inc"

	radix decimal

	constrainedToMcuInstructionFrequencyHz 8000000 ; Timing-sensitive code

	extern _powerSupplyBlankingTimer

.isrSharedData udata
	global _txUnreadCount

_txReadPtrLow res 1
_txUnreadCount res 1

.isrTxBuffer udata
	global _txBufferStart
	global _txBufferEnd
	global _txBufferPastEnd

	#if (RGBLEDS_NUMBER_OF_BYTES_IN_TX_BUFFER > 255)
		error "The ISR is written in such a way that the circular buffer must not exceed 255 bytes; this simplifies bounds checking."
	#endif

_txBufferStart res 1
	res RGBLEDS_NUMBER_OF_BYTES_IN_TX_BUFFER - 2
_txBufferEnd res 1
_txBufferPastEnd:

_adcValue res 1

_txWritePtrLow equ FSR1L_SHAD
_txWritePtrHigh equ FSR1H_SHAD

.isr code 0x0004
	global isr
	global isrTxBufferReset

isr:
	banksel PIE3
	btfss PIE3, TX1IE
	bra _checkNonTx1Interrupts

	banksel PIR3
	btfss PIR3, TX1IF
	bra _checkNonTx1Interrupts

_tx1Isr:
	banksel _txReadPtrLow ; TODO: SEE IF THIS IS OPTIMISED AWAY; IF NOT THEN REMOVE IT SINCE IT'S A SHARED BANK (USE AN ASSERTION TO ENFORCE THIS)
	movf _txReadPtrLow, W
	movwf FSR1L ; FSR1H will already hold the correct value from the mainline code since it is used as _txWritePtrHigh

_tx1BufferPossiblyEmpty:
	movf _txUnreadCount, F
	btfsc STATUS, Z
	bra _tx1BufferEmpty ; _txReadPtrLow == _txWritePtrLow && _txUnreadCount == 0, so circular buffer is empty and there are no more bytes to transmit

_tx1ReadFromCircularBuffer:
	decf _txUnreadCount, F
	banksel TX1REG
	moviw FSR1++
	movwf TX1REG

_tx1WrapAndStoreCircularBufferReadPtr:
	movlw low(_txBufferPastEnd)
	xorwf FSR1L, W
	movlw low(_txBufferStart)
	btfsc STATUS, Z
	movwf FSR1L ; _txReadPtrLow == _txBufferPastEnd, so reset the pointer to _txBufferStart

_tx1ReadFromCircularBufferCompleted:
	banksel _txReadPtrLow
	movf FSR1L, W
	movwf _txReadPtrLow
	bra _checkNonTx1Interrupts

_tx1BufferEmpty:
_disableLedBitstreamOutputOnNextByteBoundary:
	banksel CLC4POL
	bcf CLC4POL, LC4G2POL ; data

	banksel PIE3
	bcf PIE3, TX1IE

_reEnableAdcInterruptForPowerSupplyMonitoringNowTheHigherFrequencyTransmissionInterruptHasBeenDisabled:
	banksel PIE1
	bsf PIE1, ADIE

_checkNonTx1Interrupts:
	banksel ADCON0
	btfss ADCON0, ADON
	retfie

_checkForNewPowerSupplyVoltageSample:
	banksel PIR1
	btfss PIR1, ADIF
	bra _checkPowerGoodFlagOfLedPowerSwitch
	bcf PIR1, ADIF

_skipMonitoringDuringRampUpBlankingTime:
	banksel _powerSupplyBlankingTimer
	movf _powerSupplyBlankingTimer, W
	btfss STATUS, Z
	bra _powerSupplyStillRampingUp

_checkPowerSupplyVoltageIsWithinInclusiveRange:
	banksel ADRESH
	movf ADRESH, W

	banksel _adcValue ; TODO: SHOULD BE OPTIMISED AWAY
	movwf _adcValue
	sublw CONFIG_POWERMONITOR_VHIGH
	btfss STATUS, C
	bra _powerMonitoringFailure

	movlw CONFIG_POWERMONITOR_VLOW
	subwf _adcValue, W
	btfss STATUS, C
	bra _powerMonitoringFailure

_checkPowerGoodFlagOfLedPowerSwitch:
	banksel _powerSupplyBlankingTimer
	movf _powerSupplyBlankingTimer, W
	btfss STATUS, Z
	retfie

	banksel PORTB
	btfss PORTB, RB4
	bra _powerMonitoringFailure

	banksel IOCBF
	btfss IOCBF, RB4
	retfie

_powerSupplyStillRampingUp:
	decfsz _powerSupplyBlankingTimer, F
	retfie

_unmuteLedBitstreamTransmissionAndResetPowerGoodNowThatPowerSupplyHasRampedUp:
	banksel CLC4POL
	bcf CLC4POL, LC4G2POL ; data
	bcf CLC4POL, LC4G3POL ; reset

	banksel IOCBF
	bcf IOCBF, RB4
	retfie

_powerMonitoringFailure:
_disablePowerSupplyAndLedBitstreamOutputImmediately:
	pagesel powerSupplyDisable
	call powerSupplyDisable

_alsoDisableLedBitstreamTransmissionInterrupt:
	banksel PIE3
	bcf PIE3, TX1IE
	retfie


isrTxBufferReset:
	banksel _txUnreadCount
	clrf _txUnreadCount

_resetTxReadPtrToStartOfBuffer:
	banksel _txReadPtrLow
	movlw low(_txBufferStart)
	movwf _txReadPtrLow

_resetTxWritePtrToStartOfBuffer:
	banksel _txWritePtrLow
	movlw low(_txBufferStart)
	movwf _txWritePtrLow
	movwf FSR1L

_setHighByteOfTxReadAndWritePtr:
	banksel _txWritePtrHigh
	movlw high(_txBufferStart)
	movwf _txWritePtrHigh
	movwf FSR1H

	return

	end

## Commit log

2023-08-05 Initial commit. Started the schematics and threw together some firmware build files.
    [DesignCalculations.ods, kitchen-led-strips.kicad_pcb, kitchen-led-strips.kicad_sch]
2023-08-08 Further elaboration of the schematic.
    [e-case_a_dimensions.dxf, kitchen-led-strips.kicad_sch]
2023-08-09 Finalised the schematic. Ready for part numbering and checking.
    [DesignCalculations.ods, kitchen-led-strips.kicad_sch]
2023-08-09 IBIS simulation for the PIC's output driving the LED cable.
2023-08-09 Schematic tweaks and checks. Added some TODOs for tomorrow.
    [DesignCalculations.ods, kitchen-led-strips.kicad_sch]
2023-08-10 Finalised the schematic - checked over and added part numbers. Ready for layout.
    [kitchen-led-strips.kicad_sch]
2023-08-10 Started work on the PCB.
    [kitchen-led-strips.kicad_pcb, kitchen-led-strips.kicad_sch]
2023-08-11 Started the PCB layout.
    [kitchen-led-strips.kicad_pcb, kitchen-led-strips.kicad_sch]
2023-08-12 Further elaboration of the PCB.
    [kitchen-led-strips.kicad_pcb, kitchen-led-strips.kicad_sch]
2023-08-13 Further PCB elaboration. Almost ready for fabrication.
    [kitchen-led-strips.kicad_pcb, kitchen-led-strips.kicad_sch]
2023-08-14 Final PCB tweaks. Generated the gerbers for fabrication.
    [kitchen-led-strips-B_Cu.gbl, kitchen-led-strips-B_Fab.gbr, kitchen-led-strips-B_Mask.gbs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]
2023-08-14 Added the BOM and placement files for JLCPCB-with-LCSC fabrication.
    [kitchen-led-strips-bom.csv, kitchen-led-strips.kicad_pcb, kitchen-led-strips.kicad_sch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]
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2023-08-17 Added a basic rgbLedsTryShiftNext(r, g, b) function which populates the circular buffer for the UART.
    Unfortunately the UART requires bit reversal (it's LSb-first as opposed to SPI / WS2812B that are MSb-first). Bit reversal is cycle-hungry when there are only 80 cycles between UART bytes to play with (SPI timing constraints are even more restrictive due to the lack of double-buffering for the shift register).
    Due to the bit-reversal algorithm being assembler there are some hacks. CMake support for assembler isn't great. The XC8 driver / assembler is 'weird'. The best I could come up with was adding the assembly files into the linker command because I couldn't get the relocatable .objs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
2023-08-20 Added the datasheet for the actual LED controller contained on my LED strips. Slightly different to the WS2812B.
2023-08-20 Started to add in the modulator for the LEDs but realised that XC8 generates some very inefficient code - at least without the paid-for version. Going to have to rethink this approach.
2023-08-22 Initial stab at the SM16703P modulator. Basically the UART goes into the CLCs which multiplex between two PWMs for the long and short codes.
    [clc1-modulated-output.asm, initialise.asm]
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2023-08-22 Added the ISR and circular buffer that are necessary to keep the UART buffer filled at 800kbs.
2023-08-22 A basic power management initialisation routine - default all modules as disabled.
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2023-08-22 A load of hacks to wire everything together and spit out some colours to an LED strip. Perdy colours. Next step - tidy this up.
2023-08-23 Bugfix for the LED modulator timings - incorrect post-scaler and incorrect clocking edge resulted in starting the output one bit early.
    [main.asm]
2023-08-25 Fixed some labelling errors / typos on the schematic.
    [kitchen-led-strips.kicad_sch]
2023-08-25 Fixed the 'off-by-1 bit' modulation error. Also freed up a CLC for other uses.
    [clc1-modulated-output.asm, initialise.asm, isr.asm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]
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2023-08-25 Added a function for counting the number of ones in a byte, which will be required for majority voting when over-sampling the output of the infrared receiver with the UART. Also added four (unbanked)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
2023-08-28 Added an assembly-time assertion to enforce an assumption that the ISR makes.
2023-08-31 Decreased the WDT to around 4ms, which will cover a single frame.
2023-08-31 Added a basic frame-buffer for 128 RGB LEDs packed into 256 bytes as 5-bit triples. Includes basic gamma correction (y=2.2).
    [initialise.asm, main.asm, power-management.asm]
2023-09-01 Added frame synchronisation and ~32Hz blitting. Currently WIP with some debugging as trying to iron out some wrinkles in the transmission.
2023-09-02 Fixed timing synchronisation between the UART's baud rate generator and the PWM timers. They both derive from Fosc/4 but it looks like the BRG is drifting and causing the number of bits in the first 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
2023-09-02 Slight optimisation to avoid unpacking the RGB components of the current pixel more than once if there was insufficient space in the circular buffer to blit them immediately.
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2023-09-02 Added some throbbing for the green and blue LEDs to aid debugging.
2023-09-02 Made the frame-buffer size (ie. number of LEDs) an assembly-time configuration parameter.
    Added rgb-leds/next-pixel.asm to allow code external to the rgb-leds module to fill the frame-buffer in an easy / frame-buffer-agnostic way.
    Removed the throbbing debug code, but that will be shifted elsewhere.
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2023-09-03 Debugging - restored the throbber, this time using the rgbLedsFrameCounter for timing and the rgbLedsTryPutNextPixel() function for updating the frame-buffer.
2023-09-04 Re-timed to a 50Hz frame-rate to allow for interlacing LED values to provide more options for controlling luminance and hue.
2023-09-04 Quick-n-dirty hack to see the effect of interlacing LED values on hue over perceived brightness using our quantised (ie. gamma-corrected) levels.
    [main.asm]
2023-09-10 Added in-mmeory palettes for the RGB channels, of which gamma correction is one possibility.
    [initialise.asm]
2023-09-11 Migrated the LED modulator's reset logic from CLC2 to CLC4. CLC2 is required for modulating the infrared LED on RA6.
    [clc1-modulated-output.asm, initialise.asm, isr.asm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]
2023-09-11 Added a basic IR transceiver. Still WIP so there's some debugging TODOs that need to be sorted out. Also realised that v1.0 of the board has the IR receiver into RA7 but that pin cannot be PPS'd to t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
    [initialise.asm, main.asm, pins.asm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]
2023-09-12 Removed the UART TX register (CLC3) from the SM16703P modulator - the timing is such that combinational logic alone works.
    Re-purposed CLC3 as an on-chip bodge wire due to the IR receiver having UART RX wired to RA7 on the board. This is now routed via CLC3 to RB0 (previously DEBUG0) where PPS can take over.
    Added underscore prefices to the private initialisation functions of the SM16703P modulator, to normalise conventions with the other modules.
    Added board-errata.txt to keep track of the hardware issues.
    [clc1-modulated-output.asm, initialise.asm, pins.asm]
2023-09-12 Fixed the polling return values for the commands and IR transceiver modules.
    [uart2.asm]
2023-09-12 Switched from Fosc/4 to HFINTOSC for the frame-sync TIMER0 and fixed the power-saving sleep logic (for the time being).
    [power-management.asm]
2023-09-13 Setting UART2's WUE bit just before sleep. Requires a break character of at least 10 bits.
2023-09-13 Added a timeout (of [1, 2] frames, or between [20ms, 40ms]) to the IR receiver so that the state machines can be reset if incomplete packets are received. This also synchronises the 'wakeup' byte.
    [initialise.asm, main.asm]
2023-09-13 Avoiding any side-effects, such as clearing of the pre-scaler counter, that might occur by blithely setting the timer's ON bit.
2023-09-13 Stored the STATUS, PCON0 and PCON1 registers for post-reset inspection and debugging.
    [initialise.asm, main.asm]
2023-09-15 Added rgbLeds{Enable,Disable}Blitting() functions to avoid un-necessary LED refreshes.
    [initialise.asm]
2023-09-15 Added some logic to avoid un-necessary blitting when the colours are static and interlacing is disabled. This logic will not detect changes to the palette.
    [main.asm]
2023-09-17 Moved the firmware for the LED controller (slave) into 'lights-gadget' as there is another (master) firmware project, 'go-go-gadget', coming soon.
2023-09-27 Bugfix - missing banksel.
    [initialise.asm]
2023-09-27 Switched from a PIC16F15356 as used on the breadboard to a PIC16F15355 now that I have the actual board and have it stood up on the bench.
2023-10-01 Initial stab at CNC models and programs for the enclosure face-plates. WIP.
    [back-plate.dxf, front-and-back-plates.scad, front-plate.dxf]
2023-10-03 Adjustments to the enclosure face-plate models and CNC programs now that they have been machined correctly. Engraving is still to do.
    [back-plate.dxf, front-and-back-plates.scad, front-plate.dxf]
2023-10-04 Adjustments to the enclosure face-plate engraving models and CNC programs now that they have been machined correctly.
    [back-plate.dxf, front-and-back-plates.scad, front-plate.dxf]
2023-10-07 The real hardware can't be programmed with a PICKit due to the ESD protection on the programming pins so added a vscode task that copies the firmware to a Raspberry Pi (with an ICSP HAT) and uses pic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
2023-10-11 Started to investigate the filtering required for monitoring the LED voltage but it's actually less work to just do the window comparison on every ADC conversion.
2023-10-13 Added a power-supply module that enables / disables the voltage rail for the LEDs. Over-voltage of about 13.5V, under-voltage of about 10V and over-current protection (via the PG pin) are also includ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
    [DesignCalculations.ods]
2023-10-13 Added builds and skeleton configs for each of the units - one near the fridge, cooker, sink and a debug board. for bench-testing
2023-10-18 Partitioned the frame blitting and added PPS redirection to the appropriate pins. The firmware now supports one or two LED strips using a single frame buffer.
2023-10-18 Added a bunch of measurements looking at the LED data streams with an oscilloscope.
2023-10-25 Added the option to reverse the order of pixels when blitting the frame-buffer partitions. Some patterns will require this if there are two LED strips depending on their mounting direction.
    [initialise.asm]
2023-10-26 Added a better mechanism for blanking time during power-supply ramp-up. The more granular timing allows us to force-blit the first frame a few milliseconds after the supply is stable without waiting 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
    [adc-as-voltage-monitor.asm, enable.asm, initialise.asm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]
2023-10-26 Not running the (cycle-heavy) code during blitting otherwise the UART TX buffer might not get filled if rgbLedsPoll() is not called frequently enough.
2023-10-26 Had to increase the number of LEDs in the circular buffer since the polling loop is now bogged down. This needs optimising as when, say, the IR LED commands start requiring parsing, this loop is only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
